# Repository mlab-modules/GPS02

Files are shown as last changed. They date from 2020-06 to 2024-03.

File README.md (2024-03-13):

# GPS02B - MLAB Module for RTK Navigation

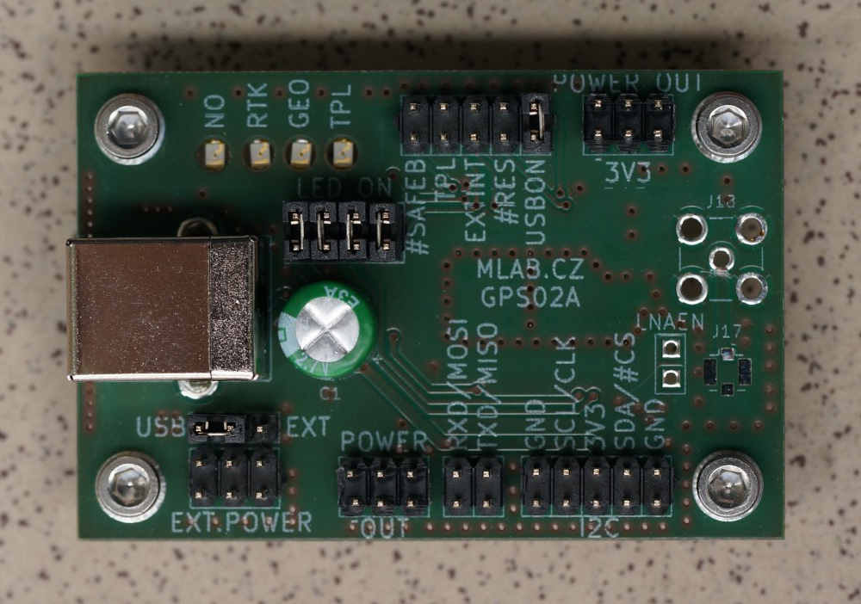
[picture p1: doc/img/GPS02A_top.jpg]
GPS02B


GPS02B is an accurate GNSS receiver module designed in the form of an MLAB module. This innovative design brings numerous advantages to the table, making it a choice for [RTK (Real-Time Kinematics)](https://en.wikipedia.org/wiki/Real-time_kinematic_positioning) navigation experiments. The GPS02B module is based on the uBlox receiver. There are multiple uBlox module types

  * [u-blox NEO-M8P](https://www.u-blox.com/en/product/neo-m8p-series) - With RTK functionality
  * [u-blox NEO-M9N](https://www.u-blox.com/en/product/neo-m9n-module) - High navigation rate GNSS module without RTK

The MLAB form factor provides several benefits for seamless integration and flexible usage. Here are some key advantages:

## Easy Integration and Compatibility

The GPS02B MLAB module follows the MLAB standard, making it easy to integrate into various MLAB-compatible systems and platforms. It ensures compatibility with other MLAB modules, allowing you to create custom configurations tailored to your specific requirements. The standardized pinout and interface simplify the process of connecting and interchanging modules within your MLAB ecosystem.

## Plug-and-Play Functionality

With its plug-and-play functionality, the GPS02B MLAB module simplifies the integration process. You can easily connect it to an MLAB system using standardized connectors, eliminating the need for complex wiring or soldering. This streamlined setup accelerates your development process and reduces time-to-market.

## Modular Expandability

The MLAB design philosophy revolves around modularity, enabling easy expansion and customization. The GPS02B module can be combined with other MLAB modules to enhance its capabilities or add new features. Whether you need additional sensors, communication interfaces, or processing power, the modular nature of MLAB allows for seamless expansion and adaptation to evolving project requirements.

## Robust and Reliable Construction

The GPS02B MLAB module is built to withstand demanding environments and provide reliable performance. Its sturdy construction ensures durability, making it suitable for applications that require long-term operation under challenging conditions. The module undergoes rigorous testing and quality control processes to deliver consistent and dependable results.

## Vast MLAB Ecosystem

By choosing the GPS02B MLAB module, you gain access to a vast ecosystem of MLAB modules and resources. The MLAB community offers a wide range of compatible modules, libraries, and development tools. You can leverage existing MLAB projects and community support to accelerate your development and benefit from the collective expertise of the MLAB community.

## Applications

The GPS02B MLAB module offers a wide range of applications in the field of RTK navigation and beyond. Here are a few examples:

- **Precision Agriculture**: Utilize the high-accuracy positioning capabilities of the GPS02B module for precise guidance of agricultural machinery, enabling optimized field operations and reduced input costs.

- **Geospatial Mapping**: Capture accurate geospatial data for surveying, mapping, and cartography applications. The GPS02B module provides reliable positioning information for creating detailed and precise maps.

- **Robotics**: Incorporate the GPS02B module into robotic systems for precise localization and navigation. Enable robots to navigate autonomously and perform tasks with high accuracy.

- **Asset Tracking**: Use the GPS02B module to track and monitor the movement of valuable assets in real-time, ensuring efficient logistics and enhanced security.

These are just a few examples of the many applications where the GPS02B MLAB module can be utilized. Its high accuracy, reliability, and compatibility with MLAB systems make it a versatile solution for a wide range of industries and projects.

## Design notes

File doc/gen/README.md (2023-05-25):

# PCB

Board size: 60.45x40.13 mm (2.38x1.58 inches)

- This is the size of the rectangle that contains the board
- Thickness: 1.6 mm (63 mils)
- Material: FR4
- Finish: None
- Layers: 2
- Copper thickness: 35 µm

Solder mask: TOP / BOTTOM

- Color: Green

Silk screen: TOP / BOTTOM

- Color: White

Stackup:

| Name | Type | Color | Thickness | Material | Epsilon_r | Loss tangent |
|---|---|---|---|---|---|---|
| F.SilkS | Top Silk Screen | | | | | |
| F.Paste | Top Solder Paste | | | | | |
| F.Mask | Top Solder Mask | Green | 10 | | | |
| F.Cu | copper | | 35 | | | |
| dielectric 1 | core | | 1510 | FR4 | 4.5 | 0.020 |
| B.Cu | copper | | 35 | | | |
| B.Mask | Bottom Solder Mask | Green | 10 | | | |
| B.Paste | Bottom Solder Paste  | | | | | |
| B.SilkS | Bottom Silk Screen | | | | | |

# Important sizes

Clearance: 0.2 mm (8 mils)

Track width: 0.4 mm (16 mils)

- By design rules: 0.4 mm (16 mils)

Drill: 0.5 mm (20 mils)

- Vias: 0.5 mm (20 mils) [Design: 0.4 mm (16 mils)]
- Pads: 0.9 mm (35 mils)
- The above values are real drill sizes, they add 0.1 mm (4 mils) to plated holes (PTH)

Via: 0.8/0.4 mm (31/16 mils)

- By design rules: 0.4/0.3 mm (16/12 mils)
- Micro via: no [0.2/0.1 mm (8/4 mils)]
- Buried/blind via: no
- Total: 192 (thru: 192 buried/blind: 0 micro: 0)

Outer Annular Ring: 0.15 mm (6 mils)

- By design rules: 0.15 mm (6 mils)

Eurocircuits class: 4B
- Using min drill 0.5 mm for an OAR of 0.15 mm

# General stats

Components count: (SMD/THT)

- Top: 0/28 (THT)
- Bottom: 35/0 (SMD)

Defined tracks:

- 0.4 mm (16 mils)
- 0.5 mm (20 mils)
- 0.6 mm (24 mils)
- 0.7 mm (28 mils)
- 0.86 mm (34 mils)
- 1.0 mm (39 mils)

Used tracks:

- 0.4 mm (16 mils) (206) defined: yes
- 0.5 mm (20 mils) (147) defined: yes
- 0.6 mm (24 mils) (34) defined: yes
- 0.7 mm (28 mils) (1) defined: yes
- 0.86 mm (34 mils) (4) defined: yes
- 1.0 mm (39 mils) (32) defined: yes

Defined vias:

- 0.8/0.4 mm (31/16 mils)

Used vias:

- 0.8/0.4 mm (31/16 mils) (Count: 192, Aspect: 2.0 A) defined: yes

Holes (excluding vias):

- 0.8 mm (31 mils) (2)
- 0.89 mm (35 mils) (55)
- 0.92 mm (36 mils) (4)
- 1.5 mm (59 mils) (1)
- 1.7 mm (67 mils) (4)
- 2.33 mm (92 mils) (2)
- 2.7 mm (106 mils) (4)
- 3.0 mm (118 mils) (4)

Oval holes:

Drill tools (including vias and computing adjusts and rounding):

- 0.5 mm (20 mils) (192)
- 0.9 mm (35 mils) (2)
- 1.0 mm (39 mils) (59)
- 1.6 mm (63 mils) (1)
- 1.8 mm (71 mils) (4)
- 2.45 mm (96 mils) (2)
- 2.7 mm (106 mils) (4)
- 3.1 mm (122 mils) (4)

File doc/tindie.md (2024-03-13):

## Unleash the Power of High-Accuracy Navigation

Discover the MLAB GPS02B, a precision GNSS (GPS) receiver module designed for Real-Time Kinematics (RTK) navigation. Embedded in the innovative [MLAB](https://www.mlab.cz/) (Modular Laboratory) form factor, the GPS02B is powered by the cutting-edge u-blox NEO-M8P receiver. It's engineered for professionals seeking unparalleled accuracy and reliability in their navigation applications.

### Key Features:

- **Seamless Integration**: Adhering to the MLAB standard, GPS02B ensures hassle-free integration into any MLAB-compatible system, fostering a plug-and-play setup that accelerates development timelines.

- **Expandability**: Embrace the modular MLAB philosophy for easy system customization. Enhance your project with additional sensors, communication interfaces, or processors, all while maintaining system coherence.

- **Durability and Reliability**: Constructed to endure, the GPS02B is your go-to module for projects demanding long-term stability in harsh conditions. It stands as a testament to unwavering performance through rigorous testing.

- **MLAB Ecosystem Access**: Tap into an extensive ecosystem of modules, libraries, and tools within the MLAB community. Benefit from shared knowledge and resources to push your projects beyond the boundaries.

### Application Domains:

- **Precision Agriculture**: Elevate farming efficiency with GPS02B's high-accuracy positioning, enabling smart guidance for agricultural machines to optimize operations and reduce costs.

- **Geospatial Mapping**: Achieve meticulous geospatial data collection for surveying and mapping, with the GPS02B ensuring the precision required for detailed cartographic outputs.

- **Advanced Robotics**: Empower robotic systems with precise localization and navigation capabilities, enabling autonomous operation and task execution with exceptional accuracy.

- **Real-Time Asset Tracking**: Implement GPS02B for steadfast tracking of valuable assets, enhancing logistics and security through real-time, accurate monitoring.

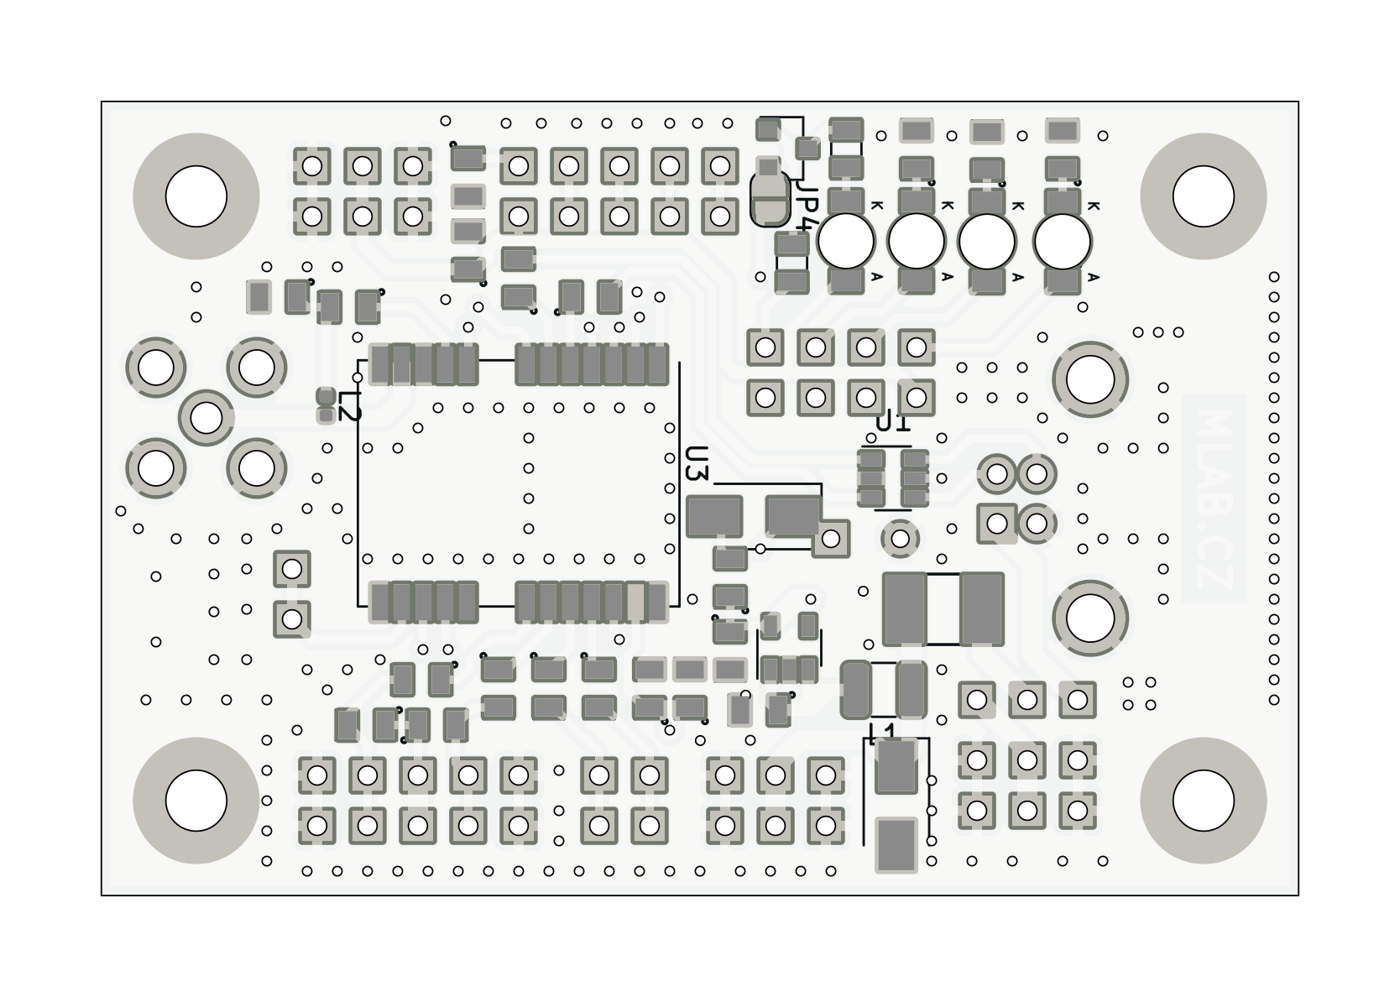
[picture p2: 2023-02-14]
doc/gen/img/GPS02B-bottom.png

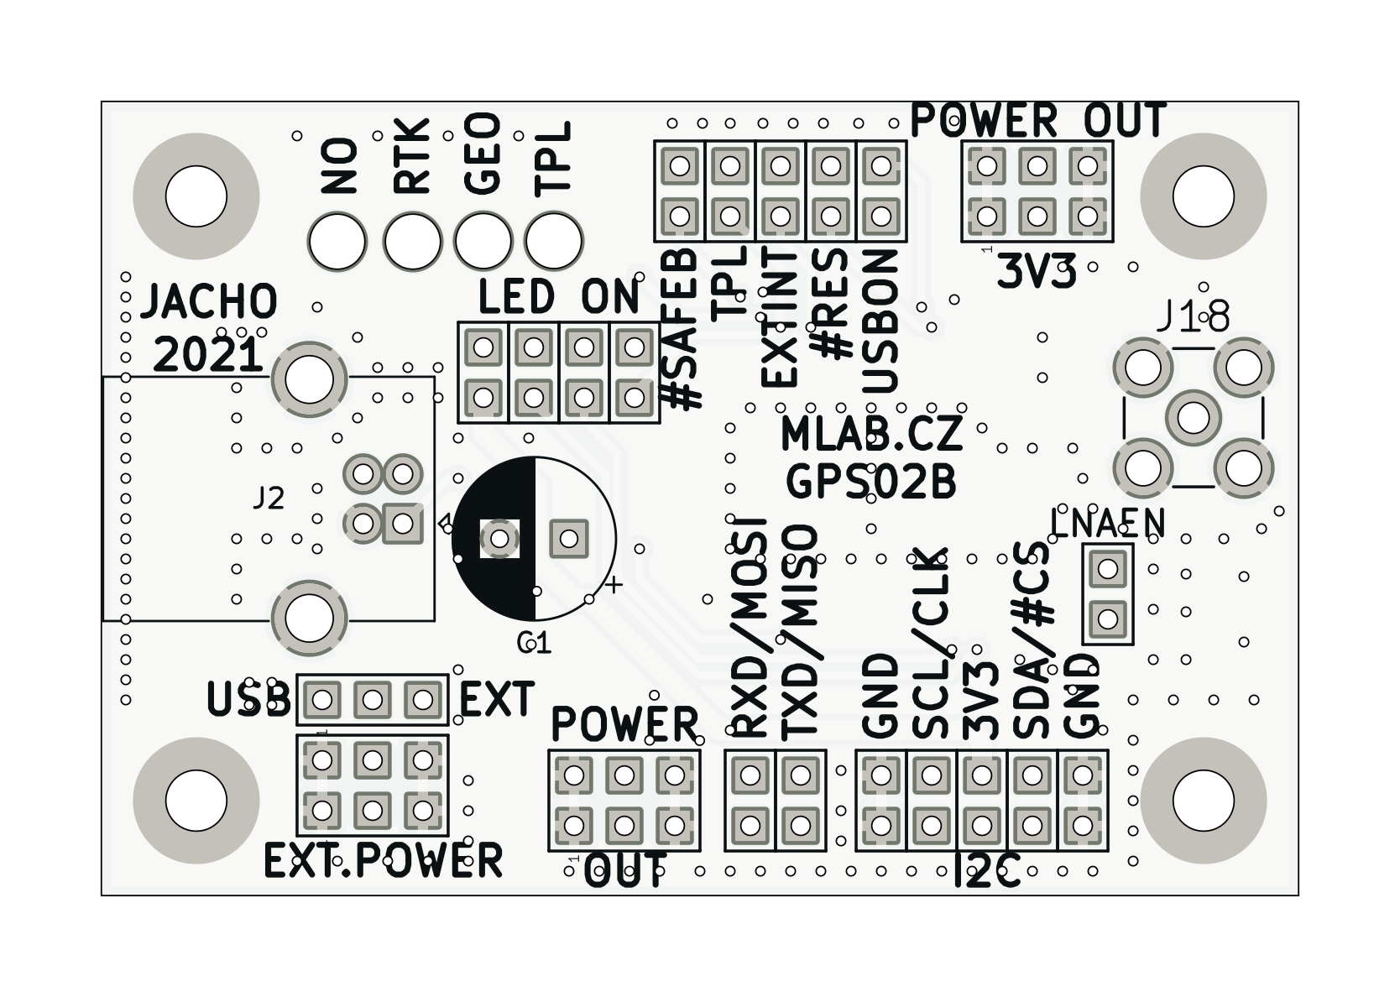
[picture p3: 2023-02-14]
doc/gen/img/GPS02B-top.png

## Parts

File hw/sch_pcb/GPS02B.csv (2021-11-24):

Source: | F:\MLAB_G\Moduly_zvlast\GPS02\hw\sch_pcb\GPS02B.kicad_sch
Date: | 24.11.2021 11:09:11
Tool: | Eeschema (5.99.0-13046-g4fe9f01eb0)
Generator: | C:\Program Files\KiCad\5.99\bin\scripting\plugins/bom_csv_grouped_by_value.py
Component Count: | 64
Individual Components:
Item | Qty | Reference(s) | Value | LibPart | Footprint | Datasheet | UST_ID
 |  | C1 | 1F | GPS02A-rescue:CP-Device | Capacitor_THT:CP_Radial_D8.0mm_P3.50mm |  | 5c70984412875079b91f8873
 |  | C2 | 10uF | GPS02A-rescue:C-Device | Mlab_R:SMD-0805 |  | 5c70984812875079b91f8bbe
 |  | C3 | 1uF | GPS02A-rescue:C-Device | Mlab_R:SMD-0805 |  | 5c70984712875079b91f8b50
 |  | C4 | 100nF | GPS02A-rescue:C-Device | Mlab_R:SMD-0805 |  | 5c70984712875079b91f8b4c
 |  | C5 | 1uF | GPS02A-rescue:C-Device | Mlab_R:SMD-0805 |  | 5c70984712875079b91f8b50
 |  | C6 | 1uF | GPS02A-rescue:C-Device | Mlab_R:SMD-0805 |  | 5c70984712875079b91f8b50
 |  | C7 | 47pF | GPS02A-rescue:C-Device | Mlab_R:SMD-0805 |  | 5c70984712875079b91f8b38
 |  | D1 | M4 | GPS02A-rescue:D_Zener-Device | Diode_SMD:D_SMA |  | 5c70984512875079b91f88ac
 |  | D2 | M4 | GPS02A-rescue:D-Device | Diode_SMD:D_SMA |  | 5c70984512875079b91f88ac
 |  | D3 | RED | GPS02A-rescue:LED-Device | Mlab_D:LED_1206 |  | 5c70984412875079b91f8896
 |  | D4 | YELLOW | GPS02A-rescue:LED-Device | Mlab_D:LED_1206 |  | 5c70984412875079b91f8897
 |  | D5 | YELLOW | GPS02A-rescue:LED-Device | Mlab_D:LED_1206 |  | 5c70984412875079b91f8897
 |  | D6 | GREEN | GPS02A-rescue:LED-Device | Mlab_D:LED_1206 |  | 5c70984412875079b91f8895
 |  | F1 | 750mA | GPS02A-rescue:Fuse-Device | Mlab_F:1812 |  | 5c70984512875079b91f88d2
 |  | J1 | HEADER_2x03_PARALLEL | MLAB_HEADER:HEADER_2x03_PARALLEL | Mlab_Pin_Headers:Straight_2x03
 |  | J2 | USB_B | GPS02A-rescue:USB_B-Connector | Connector_USB:USB_B_OST_USB-B1HSxx_Horizontal | ~ | 5c70984412875079b91f87a8
 |  | J3 | HEADER_2x03_PARALLEL | MLAB_HEADER:HEADER_2x03_PARALLEL | Mlab_Pin_Headers:Straight_2x03
 |  | J4 | HEADER_2x01_PARALLEL | MLAB_HEADER:HEADER_2x01_PARALLEL | Mlab_Pin_Headers:Straight_2x01
 |  | J5 | HEADER_2x01_PARALLEL | MLAB_HEADER:HEADER_2x01_PARALLEL | Mlab_Pin_Headers:Straight_2x01
 |  | J6 | HEADER_2x01_PARALLEL | MLAB_HEADER:HEADER_2x01_PARALLEL | Mlab_Pin_Headers:Straight_2x01
 |  | J7 | HEADER_2x01_PARALLEL | MLAB_HEADER:HEADER_2x01_PARALLEL | Mlab_Pin_Headers:Straight_2x01
 |  | J8 | HEADER_2x01_PARALLEL | MLAB_HEADER:HEADER_2x01_PARALLEL | Mlab_Pin_Headers:Straight_2x01
 |  | J9 | HEADER_2x01_PARALLEL | MLAB_HEADER:HEADER_2x01_PARALLEL | Mlab_Pin_Headers:Straight_2x01
 |  | J10 | HEADER_2x01_PARALLEL | MLAB_HEADER:HEADER_2x01_PARALLEL | Mlab_Pin_Headers:Straight_2x01
 |  | J11 | HEADER_2x01_PARALLEL | MLAB_HEADER:HEADER_2x01_PARALLEL | Mlab_Pin_Headers:Straight_2x01
 |  | J12 | HEADER_2x01_PARALLEL | MLAB_HEADER:HEADER_2x01_PARALLEL | Mlab_Pin_Headers:Straight_2x01
 |  | J13 | HEADER_2x01_PARALLEL | MLAB_HEADER:HEADER_2x01_PARALLEL | Mlab_Pin_Headers:Straight_2x01
 |  | J14 | HEADER_2x01_PARALLEL | MLAB_HEADER:HEADER_2x01_PARALLEL | Mlab_Pin_Headers:Straight_2x01
 |  | J15 | HEADER_2x03_PARALLEL | MLAB_HEADER:HEADER_2x03_PARALLEL | Mlab_Pin_Headers:Straight_2x03
 |  | J16 | HEADER_2x01_PARALLEL | MLAB_HEADER:HEADER_2x01_PARALLEL | Mlab_Pin_Headers:Straight_2x01
 |  | J18 | SMA | GPS02A-rescue:SMA-MLAB_CONNECTORS | Mlab_CON:SMA6251A13G50 |  | 5c70984412875079b91f87ac
 |  | JP1 | Jumper_3_Bridged12 | GPS02A-rescue:Jumper_3_Bridged12-Jumper | Mlab_Pin_Headers:Straight_1x03
 |  | JP2 | Jumper_2_Bridged | GPS02A-rescue:Jumper_2_Bridged-Jumper | Mlab_Pin_Headers:Straight_1x02
 |  | JP4 | Jumper_2_Open | GPS02A-rescue:Jumper_2_Open-Jumper | Jumper:SolderJumper-2_P1.3mm_Open_RoundedPad1.0x1.5mm
 |  | JP6 | Jumper_2_Bridged | GPS02A-rescue:Jumper_2_Bridged-Jumper | Mlab_Pin_Headers:Straight_1x02
 |  | JP7 | Jumper_2_Open | GPS02A-rescue:Jumper_2_Open-Jumper | Mlab_Pin_Headers:Straight_1x02
 |  | JP8 | Jumper_2_Open | GPS02A-rescue:Jumper_2_Open-Jumper | Mlab_Pin_Headers:Straight_1x02
 |  | JP9 | Jumper_2_Open | GPS02A-rescue:Jumper_2_Open-Jumper | Mlab_Pin_Headers:Straight_1x02
 |  | L1 | NL322522T-101K | GPS02A-rescue:L-Device | Inductor_SMD:L_1210_3225Metric |  | 5c70984412875079b91f87fb
 |  | L2 | 27nH | GPS02A-rescue:L-Device | Inductor_SMD:L_0402_1005Metric | LQG15HS27NJ02D | 618cbf071287506e2801ed7e
 |  | M1 | HOLE | MLAB_MECHANICAL:HOLE | Mlab_Mechanical:MountingHole_3mm
 |  | M2 | HOLE | MLAB_MECHANICAL:HOLE | Mlab_Mechanical:MountingHole_3mm
 |  | M3 | HOLE | MLAB_MECHANICAL:HOLE | Mlab_Mechanical:MountingHole_3mm
 |  | M4 | HOLE | MLAB_MECHANICAL:HOLE | Mlab_Mechanical:MountingHole_3mm
 |  | Q1 | BC817-25 | Device:Q_NPN_BEC | Package_TO_SOT_SMD:SOT-23 | ~ | 5c70984712875079b91f8aea
 |  | R1 | 22R | GPS02A-rescue:R-Device | Mlab_R:SMD-0805 |  | 5c70984512875079b91f896f
 |  | R2 | 10k | GPS02A-rescue:R-Device | Mlab_R:SMD-0805 |  | 5c70984612875079b91f899f
 |  | R3 | 10k | GPS02A-rescue:R-Device | Mlab_R:SMD-0805 |  | 5c70984612875079b91f899f
 |  | R4 | 33R | GPS02A-rescue:R-Device | Mlab_R:SMD-0805 |  | 5c70984512875079b91f8970
 |  | R5 | 33R | GPS02A-rescue:R-Device | Mlab_R:SMD-0805 |  | 5c70984512875079b91f8970
 |  | R6 | 33R | GPS02A-rescue:R-Device | Mlab_R:SMD-0805 |  | 5c70984512875079b91f8970
 |  | R7 | 33R | GPS02A-rescue:R-Device | Mlab_R:SMD-0805 |  | 5c70984512875079b91f8970
 |  | R8 | 33R | GPS02A-rescue:R-Device | Mlab_R:SMD-0805 |  | 5c70984512875079b91f8970
 |  | R9 | 33R | GPS02A-rescue:R-Device | Mlab_R:SMD-0805 |  | 5c70984512875079b91f8970
 |  | R10 | 620R | GPS02A-rescue:R-Device | Mlab_R:SMD-0805 |  | 5c70984512875079b91f8989
 |  | R11 | 10R | GPS02A-rescue:R-Device | Mlab_R:SMD-0805 |  | 5c70984512875079b91f896d
 |  | R12 | 620R | GPS02A-rescue:R-Device | Mlab_R:SMD-0805 |  | 5c70984512875079b91f8989
 |  | R13 | 620R | GPS02A-rescue:R-Device | Mlab_R:SMD-0805 |  | 5c70984512875079b91f8989
 |  | R14 | 220R | Device:R | Mlab_R:SMD-0805 | ~ | 5c70984512875079b91f897f
 |  | R15 | 10k | GPS02A-rescue:R-Device | Mlab_R:SMD-0805 |  | 5c70984612875079b91f899f
 |  | R16 | 220R | Device:R | Mlab_R:SMD-0805 | ~ | 5c70984512875079b91f897f
 |  | U1 | USBLC6-2SC6 | GPS02A-rescue:USBLC6-2SC6-Power_Protection | Package_TO_SOT_SMD:SOT-23-6 | http://www2.st.com/resource/en/datasheet/CD00050750.pdf | 5e82e0691287502a334a778c
 |  | U2 | MIC5504-3.3YM5 | GPS02A-rescue:MIC5504-3.3YM5-Regulator_Linear | Package_TO_SOT_SMD:SOT-23-5 | http://ww1.microchip.com/downloads/en/DeviceDoc/MIC550X.pdf | 5c7255e81287500b4e112ea2
 |  | U3 | NEO-M8P | GPS02A-rescue:NEO-M8P-RF_GPS | RF_GPS:ublox_NEO | https://www.u-blox.com/sites/default/files/NEO-M8P_DataSheet_%28UBX-15016656%29.pdf | 5ed7ad5612875004e15a62f5
Collated Components:
Item | Qty | Reference(s) | Value | LibPart | Footprint | Datasheet | UST_ID
1 | 1 | C1 | 1F | GPS02A-rescue:CP-Device | Capacitor_THT:CP_Radial_D8.0mm_P3.50mm |  | 5c70984412875079b91f8873
2 | 1 | C2 | 10uF | GPS02A-rescue:C-Device | Mlab_R:SMD-0805 |  | 5c70984812875079b91f8bbe
3 | 3 | C3, C5, C6 | 1uF | GPS02A-rescue:C-Device | Mlab_R:SMD-0805 |  | 5c70984712875079b91f8b50
4 | 1 | C4 | 100nF | GPS02A-rescue:C-Device | Mlab_R:SMD-0805 |  | 5c70984712875079b91f8b4c
5 | 1 | C7 | 47pF | GPS02A-rescue:C-Device | Mlab_R:SMD-0805 |  | 5c70984712875079b91f8b38
6 | 1 | D1 | M4 | GPS02A-rescue:D_Zener-Device | Diode_SMD:D_SMA |  | 5c70984512875079b91f88ac
7 | 1 | D2 | M4 | GPS02A-rescue:D-Device | Diode_SMD:D_SMA |  | 5c70984512875079b91f88ac
8 | 1 | D3 | RED | GPS02A-rescue:LED-Device | Mlab_D:LED_1206 |  | 5c70984412875079b91f8896
9 | 2 | D4, D5 | YELLOW | GPS02A-rescue:LED-Device | Mlab_D:LED_1206 |  | 5c70984412875079b91f8897
10 | 1 | D6 | GREEN | GPS02A-rescue:LED-Device | Mlab_D:LED_1206 |  | 5c70984412875079b91f8895
11 | 1 | F1 | 750mA | GPS02A-rescue:Fuse-Device | Mlab_F:1812 |  | 5c70984512875079b91f88d2
12 | 3 | J1, J3, J15 | HEADER_2x03_PARALLEL | MLAB_HEADER:HEADER_2x03_PARALLEL | Mlab_Pin_Headers:Straight_2x03
13 | 1 | J2 | USB_B | GPS02A-rescue:USB_B-Connector | Connector_USB:USB_B_OST_USB-B1HSxx_Horizontal | ~ | 5c70984412875079b91f87a8
14 | 12 | J4, J5, J6, J7, J8, J9, J10, J11, J12, J13, J14, J16 | HEADER_2x01_PARALLEL | MLAB_HEADER:HEADER_2x01_PARALLEL | Mlab_Pin_Headers:Straight_2x01
15 | 1 | J18 | SMA | GPS02A-rescue:SMA-MLAB_CONNECTORS | Mlab_CON:SMA6251A13G50 |  | 5c70984412875079b91f87ac
16 | 1 | JP1 | Jumper_3_Bridged12 | GPS02A-rescue:Jumper_3_Bridged12-Jumper | Mlab_Pin_Headers:Straight_1x03
17 | 2 | JP2, JP6 | Jumper_2_Bridged | GPS02A-rescue:Jumper_2_Bridged-Jumper | Mlab_Pin_Headers:Straight_1x02
18 | 1 | JP4 | Jumper_2_Open | GPS02A-rescue:Jumper_2_Open-Jumper | Jumper:SolderJumper-2_P1.3mm_Open_RoundedPad1.0x1.5mm
19 | 3 | JP7, JP8, JP9 | Jumper_2_Open | GPS02A-rescue:Jumper_2_Open-Jumper | Mlab_Pin_Headers:Straight_1x02
20 | 1 | L1 | NL322522T-101K | GPS02A-rescue:L-Device | Inductor_SMD:L_1210_3225Metric |  | 5c70984412875079b91f87fb
21 | 1 | L2 | 27nH | GPS02A-rescue:L-Device | Inductor_SMD:L_0402_1005Metric | LQG15HS27NJ02D | 618cbf071287506e2801ed7e
22 | 4 | M1, M2, M3, M4 | HOLE | MLAB_MECHANICAL:HOLE | Mlab_Mechanical:MountingHole_3mm
23 | 1 | Q1 | BC817-25 | Device:Q_NPN_BEC | Package_TO_SOT_SMD:SOT-23 | ~ | 5c70984712875079b91f8aea
24 | 1 | R1 | 22R | GPS02A-rescue:R-Device | Mlab_R:SMD-0805 |  | 5c70984512875079b91f896f
25 | 3 | R2, R3, R15 | 10k | GPS02A-rescue:R-Device | Mlab_R:SMD-0805 |  | 5c70984612875079b91f899f
26 | 6 | R4, R5, R6, R7, R8, R9 | 33R | GPS02A-rescue:R-Device | Mlab_R:SMD-0805 |  | 5c70984512875079b91f8970
27 | 3 | R10, R12, R13 | 620R | GPS02A-rescue:R-Device | Mlab_R:SMD-0805 |  | 5c70984512875079b91f8989
28 | 1 | R11 | 10R | GPS02A-rescue:R-Device | Mlab_R:SMD-0805 |  | 5c70984512875079b91f896d
29 | 2 | R14, R16 | 220R | Device:R | Mlab_R:SMD-0805 | ~ | 5c70984512875079b91f897f
30 | 1 | U1 | USBLC6-2SC6 | GPS02A-rescue:USBLC6-2SC6-Power_Protection | Package_TO_SOT_SMD:SOT-23-6 | http://www2.st.com/resource/en/datasheet/CD00050750.pdf | 5e82e0691287502a334a778c
31 | 1 | U2 | MIC5504-3.3YM5 | GPS02A-rescue:MIC5504-3.3YM5-Regulator_Linear | Package_TO_SOT_SMD:SOT-23-5 | http://ww1.microchip.com/downloads/en/DeviceDoc/MIC550X.pdf | 5c7255e81287500b4e112ea2
32 | 1 | U3 | NEO-M8P | GPS02A-rescue:NEO-M8P-RF_GPS | RF_GPS:ublox_NEO | https://www.u-blox.com/sites/default/files/NEO-M8P_DataSheet_%28UBX-15016656%29.pdf | 5ed7ad5612875004e15a62f5

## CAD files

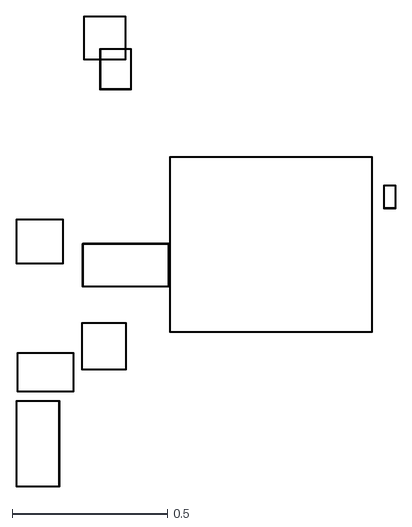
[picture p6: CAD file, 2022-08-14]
doc/gen/dxf/GPS02B-B_Courtyard.dxf
1.22 x 1.51

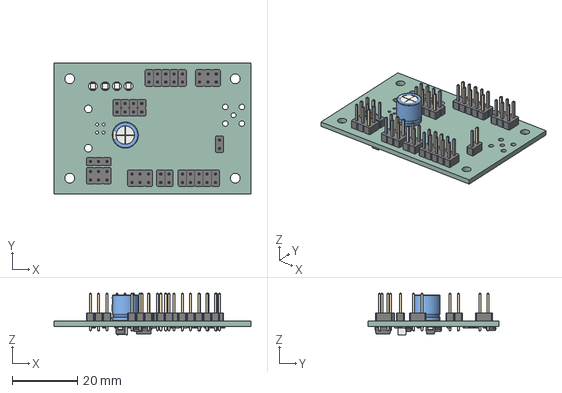
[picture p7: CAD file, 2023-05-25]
doc/gen/GPS02B.step
60.5 x 40.1 x 12.7 mm
tmpdh7f3xjg PCB

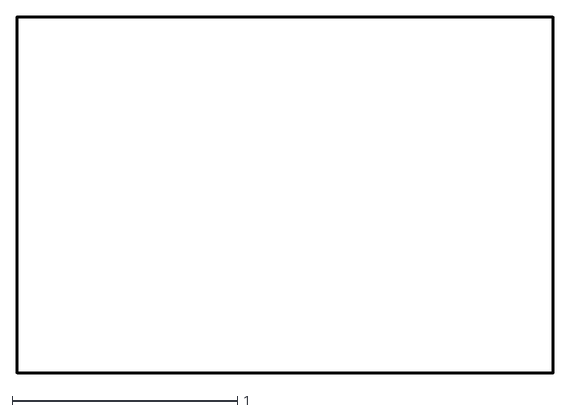
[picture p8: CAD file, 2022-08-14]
doc/gen/dxf/GPS02B-Edge_Cuts.dxf
2.39 x 1.59

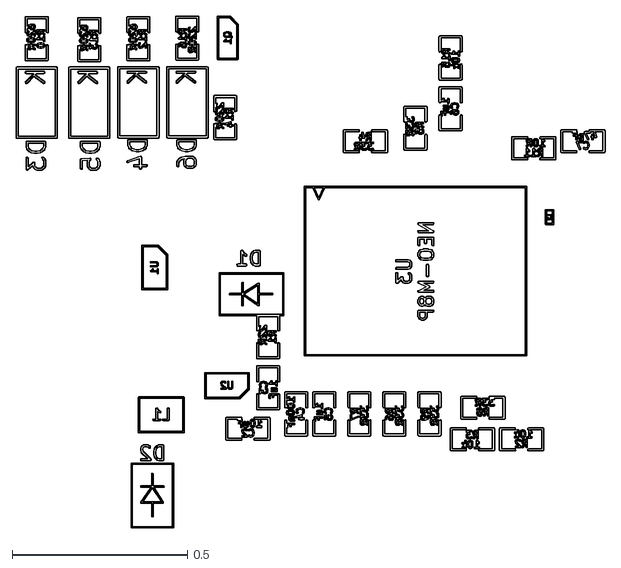
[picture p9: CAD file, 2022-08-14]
doc/gen/dxf/GPS02B-B_Fab.dxf
1.68 x 1.46

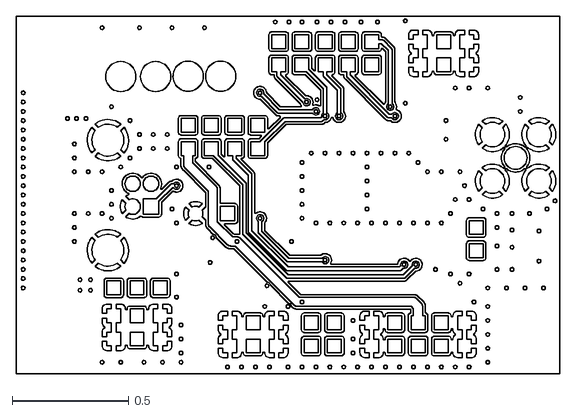
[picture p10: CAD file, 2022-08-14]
doc/gen/dxf/GPS02B-F_Cu.dxf
2.34 x 1.54

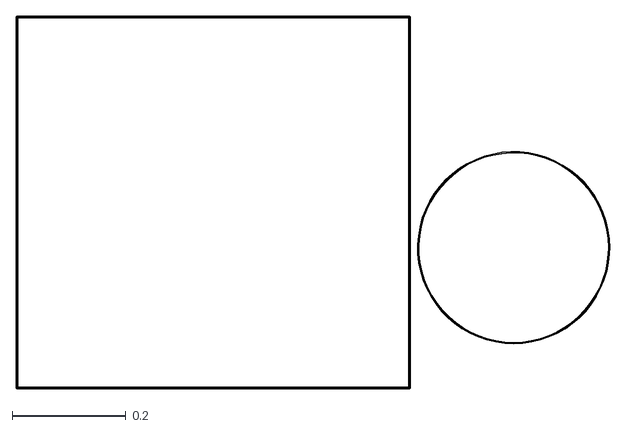
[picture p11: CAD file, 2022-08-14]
doc/gen/dxf/GPS02B-F_Courtyard.dxf
1.04 x 0.653

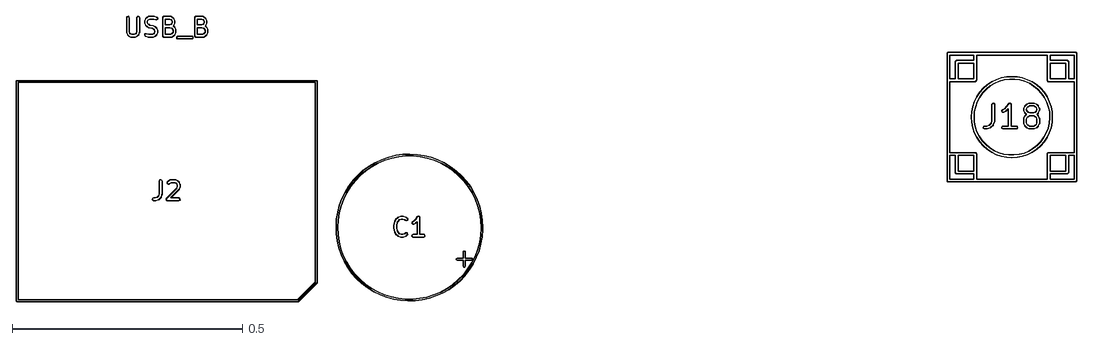
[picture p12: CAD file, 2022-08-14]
doc/gen/dxf/GPS02B-F_Fab.dxf
2.30 x 0.62

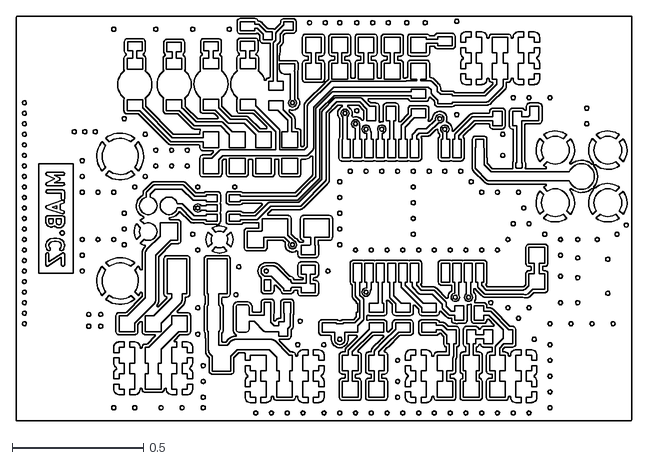
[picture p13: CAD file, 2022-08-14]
doc/gen/dxf/GPS02B-B_Cu.dxf
2.34 x 1.54

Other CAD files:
doc/gen/dxf/GPS02B-Margin.dxf
doc/gen/dxf/GPS02B-B_Mask.dxf
doc/gen/dxf/GPS02B-B_Paste.dxf
doc/gen/dxf/GPS02B-B_Silkscreen.dxf
doc/gen/dxf/GPS02B-F_Mask.dxf
doc/gen/dxf/GPS02B-F_Paste.dxf
doc/gen/dxf/GPS02B-F_Silkscreen.dxf

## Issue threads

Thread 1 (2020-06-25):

Připojení GPS antény

kaklik, 2020-06-25:
GPS anténa má na modulu možnost připojení přes SMA konektor a U.fl konektor.

@ChroustJan  při výrobě odrvrtal prostřední pin, protože otvor v KiCAD knihovnách je pro skladovou verzi SMA konektoru příliš malý.

Během výroby modulu jsme se ale rozhodli začít používat konektory [MCX](https://en.wikipedia.org/wiki/MCX_connector). Které ale mají středový pin s menším průměrem. Odvrtávání tak pravděpodobně není potřeba.

Před přiletováním MCX konektoru jsem proškrabal cestičku k ploškám U.fl, aby zbytečně nekazila parametry přívodu.

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

ChroustJan, 2021-03-14:
@kaklik co s tímto issues?

kaklik, 2021-03-14:
> @kaklik co s tímto issues?

Smazat u.fl konektor a nějak optimalizovat průměr otvoru pro středový pin.

ChroustJan, 2021-03-14:
@kaklik a to tedy u.fl konektor vyřazujeme?

kaklik, 2021-03-14:
> @kaklik a to tedy u.fl konektor vyřazujeme?

Já pro u.fl konektor nevidím na MLAB modulech využití..  Ty jsi ho někdy někde použil?

ChroustJan, 2021-03-15:
@kaklik  mělo to být řešení pro zařízení, aby se nepovolovalo SMA, ale tohle v zásadě řeší i ten nový konektor. Prodávají se k němu i redukce o 90stupňů? Aby se nám to pak vešlo do Al krabičky.

kaklik, 2021-06-20:
> @kaklik mělo to být řešení pro zařízení, aby se nepovolovalo SMA, ale tohle v zásadě řeší i ten nový konektor. Prodávají se k němu i redukce o 90stupňů? Aby se nám to pak vešlo do Al krabičky.

Tenhle problém myslím řeší nové MLAB kabely se zahnutými MCX konektory z výroby.

ChroustJan, 2021-07-20:
U.fl konektor odstraněn.

Closed 2021-07-20.

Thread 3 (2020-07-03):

Přebíjení zálohovacího kondenzátoru

kaklik, 2020-07-03:
Zálohovací kondenzátor je nabíjen na hodnotu 3.07 V. Maximální přípustná hodnota napětí na kondezátoru však je 2.7 V

Příčinou přebíjení je fakt, že kondenzátor je nabíjen přes shottkyho diodu BAS85, která má napěťový úbytek pouze 0.2V

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

K odstranění tohoto problému je nutné použít nějakou normální křemíkovou diodu s napěťovým úbytkem alespoň 0.5V.

ChroustJan, 2020-07-08:
Tak už víme, proč tam byla ta jiná dioda, která se ti nezdála.

ChroustJan, 2021-07-20:
Aplikována dioda M4

Closed 2021-07-20.

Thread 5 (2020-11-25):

Upravit otvor pro SMA konektor

ChroustJan, 2020-11-25:
Upravit otvory na SMA dle starých MLAB knihoven.

Viz issue #1

kaklik, 2020-11-25:
Proč? Teď máme stejně MCX..

ChroustJan, 2020-11-25:
Považuji za rozumné mít tu možnost. Nevychází to o chlup. Kicad má pro nás nevyhovující knihovnu.

ChroustJan, 2021-07-20:
Provedeno.

Closed 2021-07-20.

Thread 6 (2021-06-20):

Napájení aktivní antény

kaklik, 2021-06-20:
Při experimentech se ukázalo, že GNSS přijímač NEO-M8P má časté výpadky fixu. S tím, že úroveň signálu se celou dobu provozu drží mírně nad hranicí navigace.

Z konstrukčního pohledu je podezřelý způsob, kterým je vyřešeno napájení aktivní antény. Ve schéma je tento obvod:

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

Na PCB je zapojení realizováno tímto layoutem:

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

Zapojení je pravděpodobně  převzato z [aplikačního manuálu NEO-M8P](https://www.u-blox.com/en/docs/UBX-15028081), kde je následující obrázek:
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

Ten odkazuje jednak na záležitost, že je vhodné dát na vstup RF_IN střídavou vazbu, aby byl vstup lépe ESD ochráněn. (popsáno v sekci 3.3 Figure  11: ESD precautions)

A potom také odkazuje na tabulku doporučených hodnot součástek:

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

Z tabulky je vidět, že zřejména použitý kondenzátor zjevně nesplňuje doporučené parametry, neboť tabulka uvažuje kapacitu o hodnotě 47pF místo 10nF, což je celkem očekávatelné vzhledem k doporučené hodnotě indukčnosti. Kde se na cívku kromě doporučené hodnoty 27nH klade ještě další požadavek, aby měla impedanci větší než 500 ohm na potřebných GPS frekvencích.

Celkově je tak potřeba:

- [ ] Posunout cívku L2 tak, aby co nejméně narušovala RF cestu k anténě
- [ ] Změnit hodnotu kondenzátoru C7 na 47pF
- [ ] Ověřit katalogové parametry použité cívky.

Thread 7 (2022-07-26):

RTK_STAT LED inverted

kaklik, 2022-07-26:
There should be an inverting transistor on RTK_STAT output. It is because the RTK LED light up after power up, then blinks, and in the RTK fixed mode switch off.

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

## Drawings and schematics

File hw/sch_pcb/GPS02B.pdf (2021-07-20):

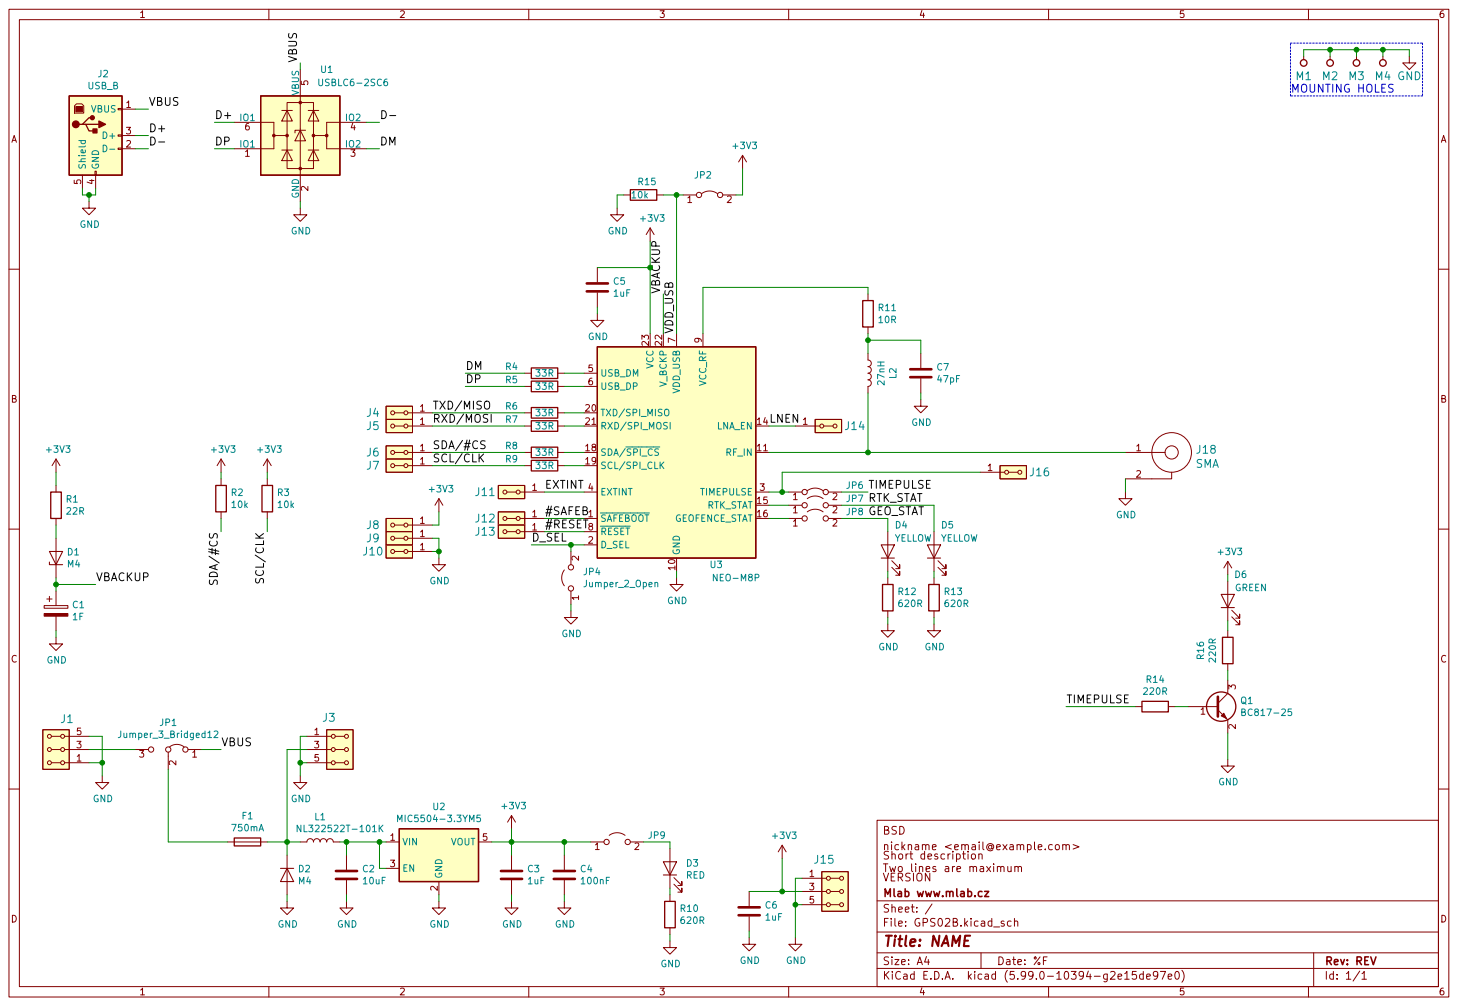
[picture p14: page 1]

nickname <email@example.com> BSD

Short description
File: GPS02B.kicad_sch Sheet: / Mlab www.mlab.cz VERSION

Two lines are maximum

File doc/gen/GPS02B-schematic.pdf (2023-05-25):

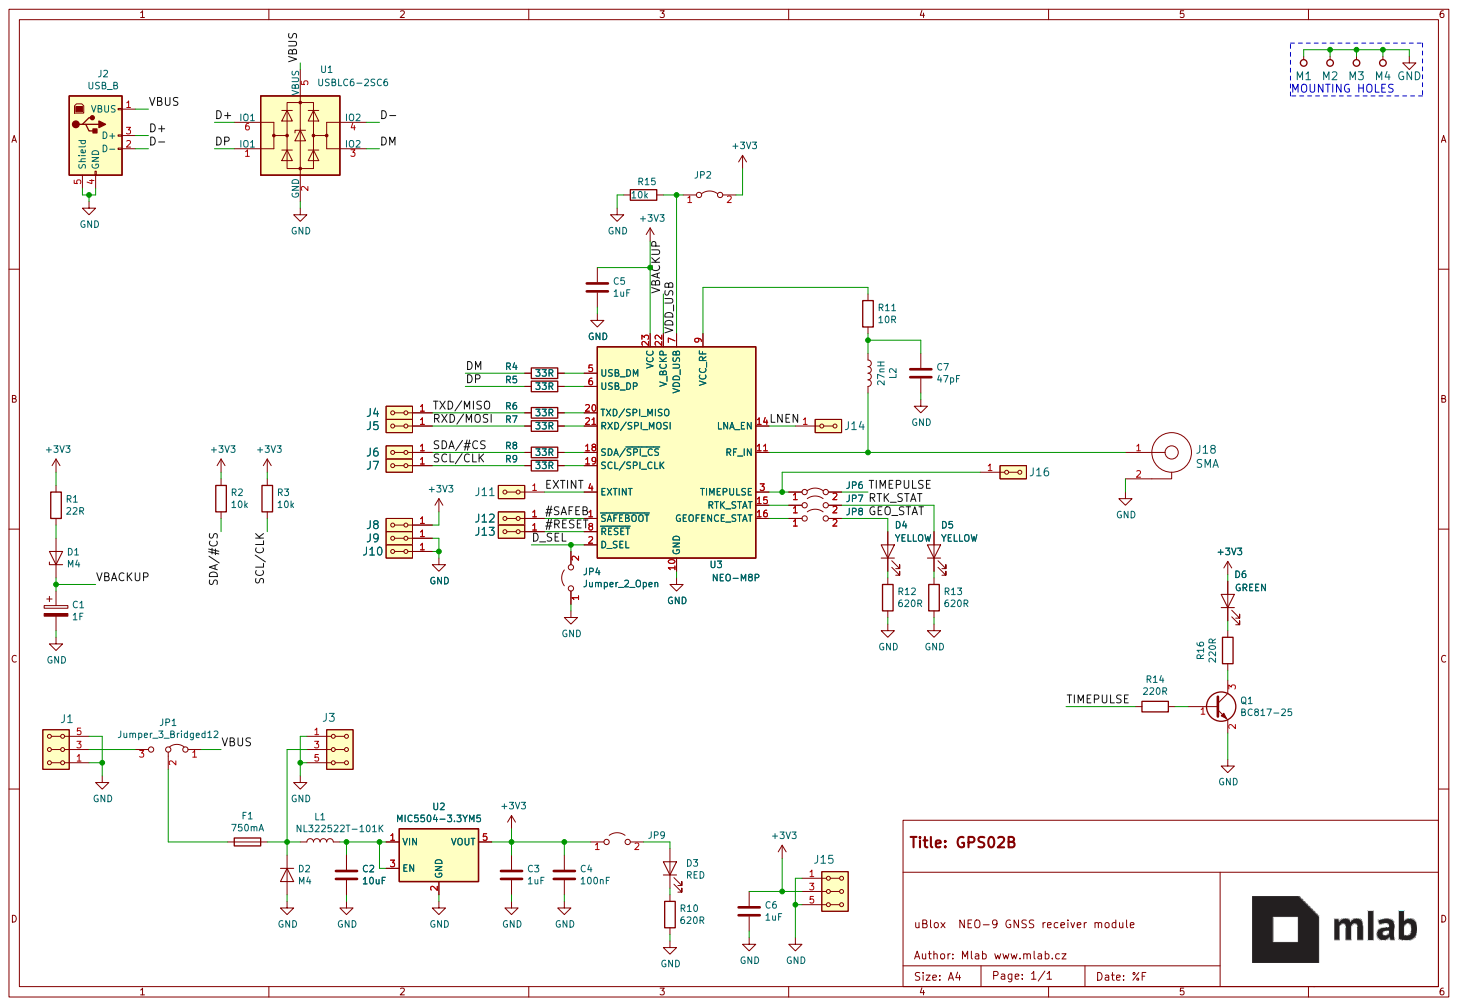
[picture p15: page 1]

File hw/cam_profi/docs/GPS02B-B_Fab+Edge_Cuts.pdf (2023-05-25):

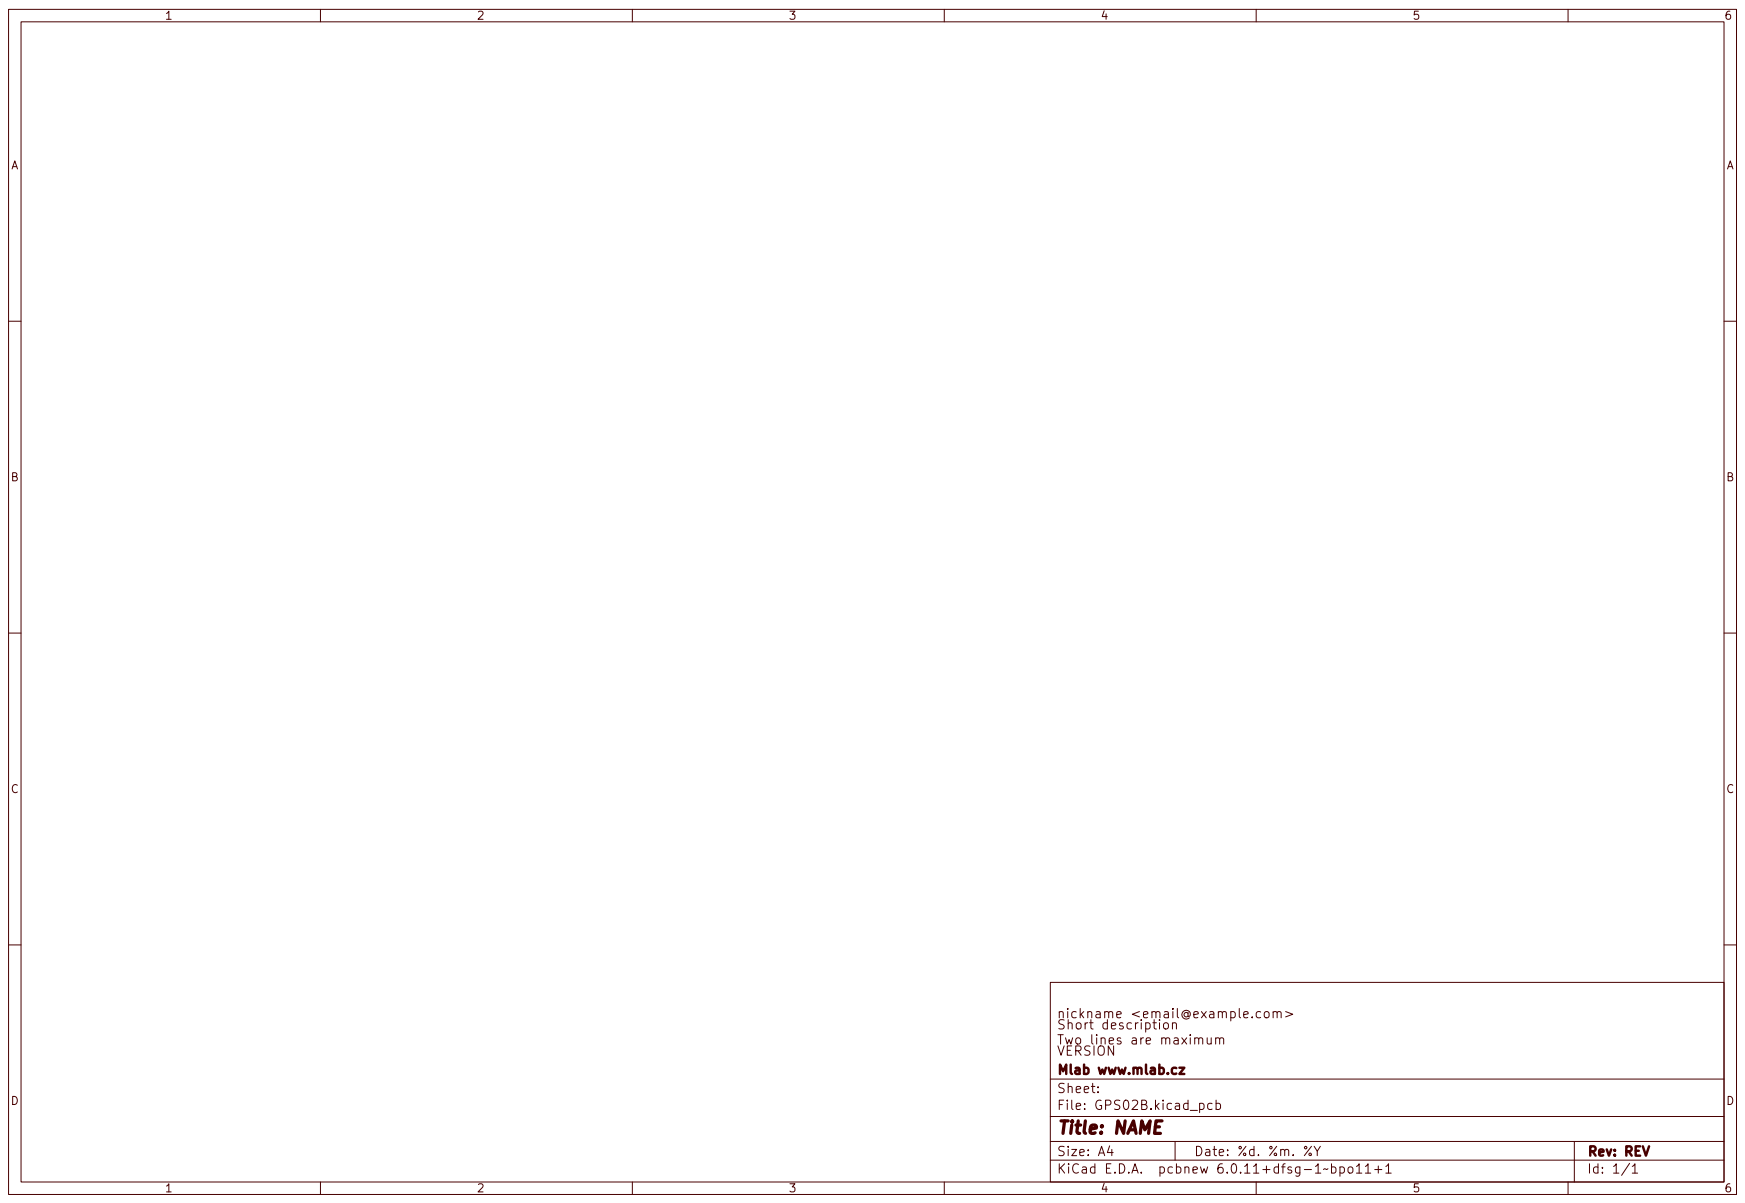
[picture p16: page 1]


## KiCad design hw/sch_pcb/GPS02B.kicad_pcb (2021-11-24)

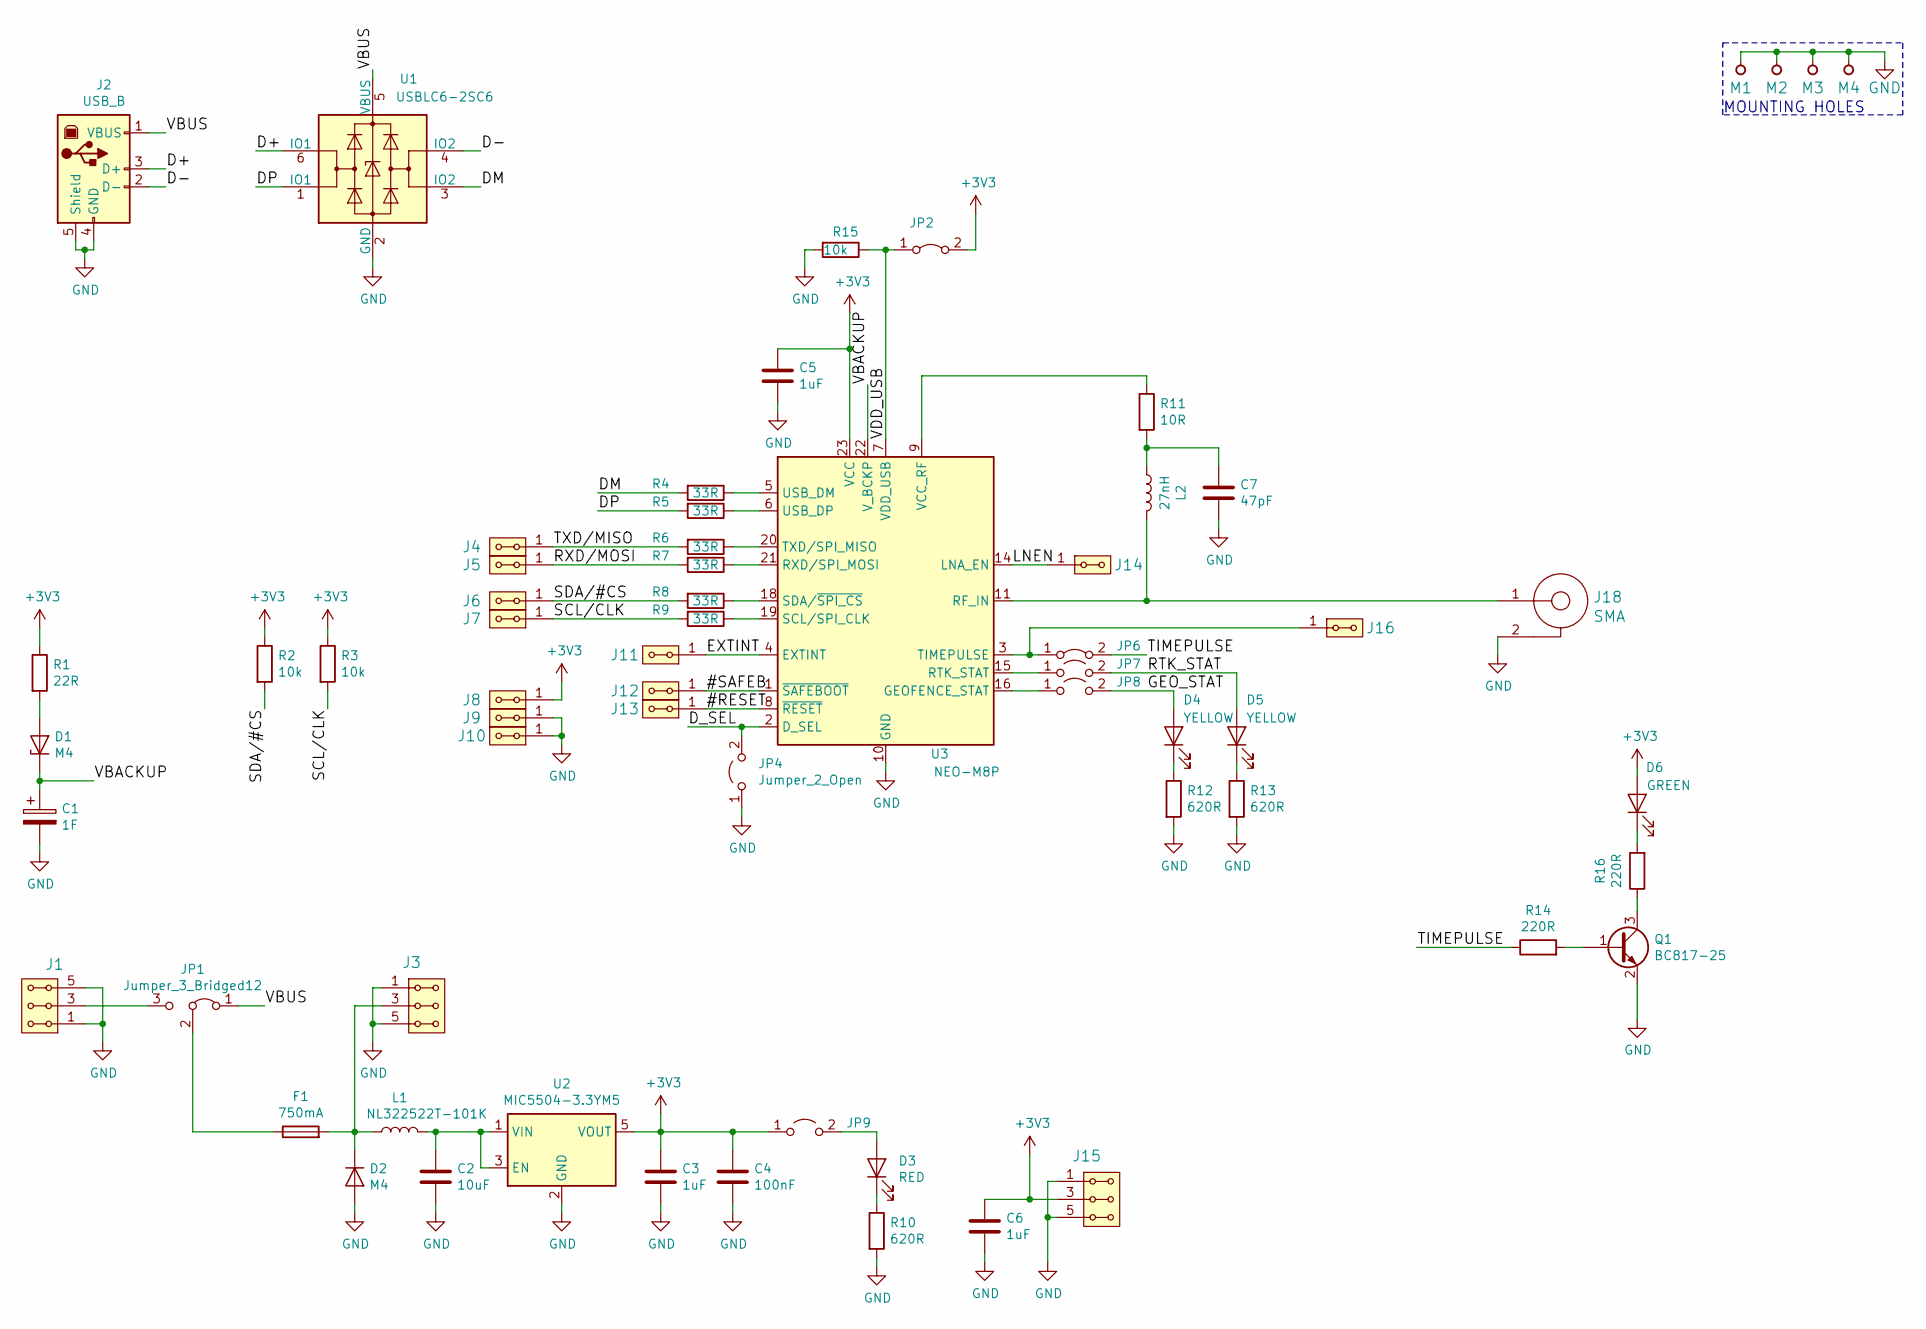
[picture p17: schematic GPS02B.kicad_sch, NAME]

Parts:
C1: 1F; CP_Radial_D8.0mm_P3.50mm
C2: 10uF; SMD-0805
C3, C5, C6: 1uF; SMD-0805
C4: 100nF; SMD-0805
C7: 47pF; SMD-0805
D1, D2: M4; D_SMA
D3: RED; LED_1206
D4, D5: YELLOW; LED_1206
D6: GREEN; LED_1206
F1: 750mA; 1812
J1, J3, J15: HEADER_2x03_PARALLEL; Straight_2x03
J2: USB_B; USB_B_OST_USB-B1HSxx_Horizontal
J4, J5, J6, J7, J8, J9, J10, J11, J12, J13, J14, J16: HEADER_2x01_PARALLEL; Straight_2x01
J18: SMA; SMA6251A13G50
JP1: Jumper_3_Bridged12; Straight_1x03
JP2, JP6: Jumper_2_Bridged; Straight_1x02
JP4: Jumper_2_Open; SolderJumper-2_P1.3mm_Open_RoundedPad1.0x1.5mm
JP7, JP8, JP9: Jumper_2_Open; Straight_1x02
L1: NL322522T-101K; L_1210_3225Metric
L2: 27nH; L_0402_1005Metric
M1, M2, M3, M4: HOLE; MountingHole_3mm
Q1: BC817-25; SOT-23
R1: 22R; SMD-0805
R2, R3, R15: 10k; SMD-0805
R4, R5, R6, R7, R8, R9: 33R; SMD-0805
R10, R12, R13: 620R; SMD-0805
R11: 10R; SMD-0805
R14, R16: 220R; SMD-0805
U1: USBLC6-2SC6; SOT-23-6
U2: MIC5504-3.3YM5; SOT-23-5
U3: NEO-M8P; ublox_NEO

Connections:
+3V3: C3.1, C4.1, C5.1, C6.1, D6.2 (A), J8.1, J8.2, J15.3, J15.4, JP2.2 (B), JP9.1 (A), R1.1, R2.1, R3.1, U2.5 (VOUT), U3.23 (VCC)
/#RESET: J13.1, J13.2, U3.8 (~RESET)
/#SAFEB: J12.1, J12.2, U3.1 (~SAFEBOOT)
/D+: J2.3 (D+), U1.6 (IO1)
/D-: J2.2 (D-), U1.4 (IO2)
/DM: R4.2, U1.3 (IO2)
/DP: R5.2, U1.1 (IO1)
/D_SEL: JP4.2 (B), U3.2 (D_SEL)
/EXTINT: J11.1, J11.2, U3.4 (EXTINT)
/GEO_STAT: D4.2 (A), JP8.2 (B)
/LNEN: J14.1, J14.2, U3.14 (LNA_EN)
/RTK_STAT: D5.2 (A), JP7.2 (B)
/RXD/MOSI: J5.1, J5.2, R7.2
/SCL/CLK: J7.1, J7.2, R3.2, R9.2
/SDA/#CS: J6.1, J6.2, R2.2, R8.2
/TIMEPULSE: JP6.2 (B), R14.1
/TXD/MISO: J4.1, J4.2, R6.2
/VBACKUP: C1.1, D1.1 (K), U3.22 (V_BCKP)
/VBUS: J2.1 (VBUS), JP1.1 (A), U1.5 (VBUS)
/VDD_USB: JP2.1 (A), R15.1, U3.7 (VDD_USB)
GND: C1.2, C2.2, C3.2, C4.2, C5.2, C6.2, C7.2, D2.2 (A), J1.1, J1.2, J1.5, J1.6, J2.4 (GND), J2.5 (Shield), J3.1, J3.2, J3.5, J3.6, J9.1, J9.2, J10.1, J10.2, J15.1, J15.2, J15.5, J15.6, J18.2, JP4.1 (A), M1.1, M2.1, M3.1, M4.1, Q1.2 (E), R10.2, R12.2, R13.2, R15.2, U1.2 (GND), U2.2 (GND), U3.10 (GND), U3.12 (GND), U3.13 (GND), U3.24 (GND)
unnamed: C2.1, L1.2, U2.1 (VIN), U2.3 (EN)
unnamed: C7.1, L2.1, R11.2
unnamed: D1.2 (A), R1.2
unnamed: D2.1 (K), F1.2, J3.3, J3.4, L1.1
unnamed: D3.1 (K), R10.1
unnamed: D3.2 (A), JP9.2 (B)
unnamed: D4.1 (K), R12.1
unnamed: D5.1 (K), R13.1
unnamed: D6.1 (K), R16.2
unnamed: F1.1, JP1.2 (C)
unnamed: J1.3, J1.4, JP1.3 (B)
unnamed: J16.1, J16.2, JP6.1 (A), U3.3 (TIMEPULSE)
unnamed: J18.1, L2.2, U3.11 (RF_IN)
unnamed: JP7.1 (A), U3.15 (RTK_STAT)
unnamed: JP8.1 (A), U3.16 (GEOFENCE_STAT)
unnamed: Q1.1 (B), R14.2
unnamed: Q1.3 (C), R16.1
unnamed: R4.1, U3.5 (USB_DM)
unnamed: R5.1, U3.6 (USB_DP)
unnamed: R6.1, U3.20 (TXD/SPI_MISO)
unnamed: R7.1, U3.21 (RXD/SPI_MOSI)
unnamed: R8.1, U3.18 (SDA/~SPI_CS)
unnamed: R9.1, U3.19 (SCL/SPI_CLK)
unnamed: R11.1, U3.9 (VCC_RF)

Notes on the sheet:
MOUNTING HOLES

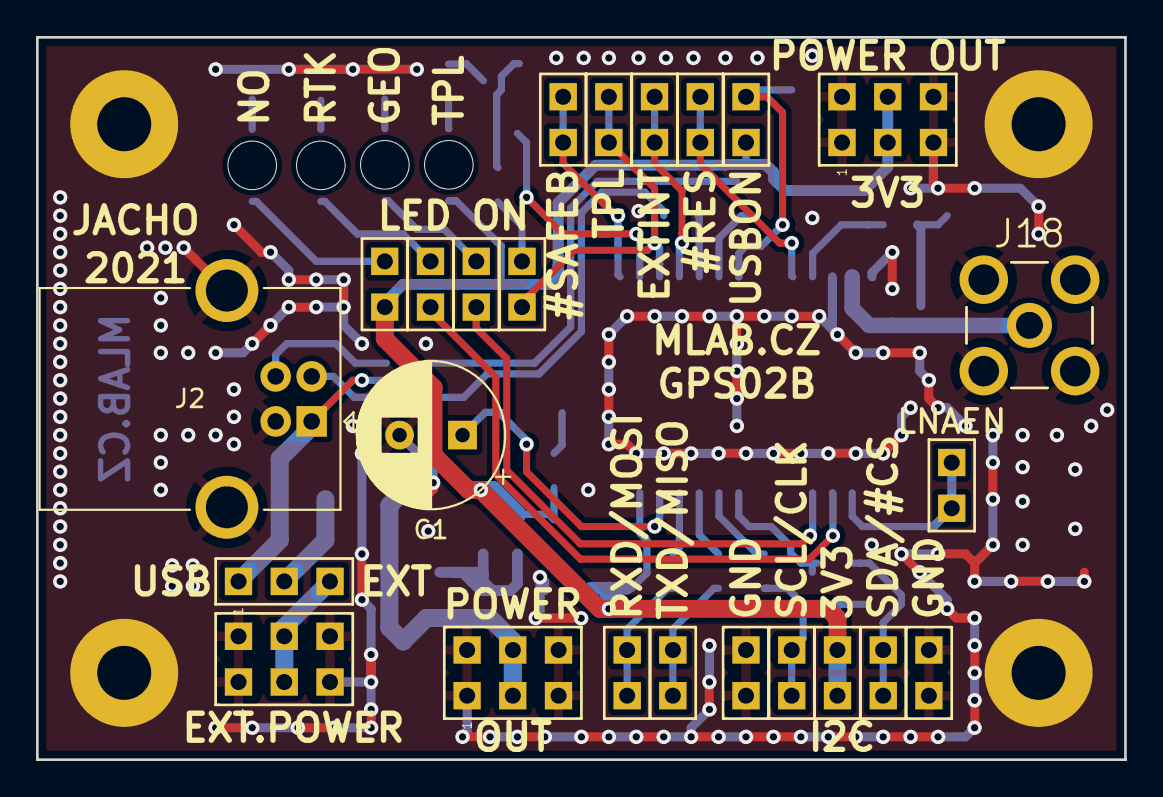
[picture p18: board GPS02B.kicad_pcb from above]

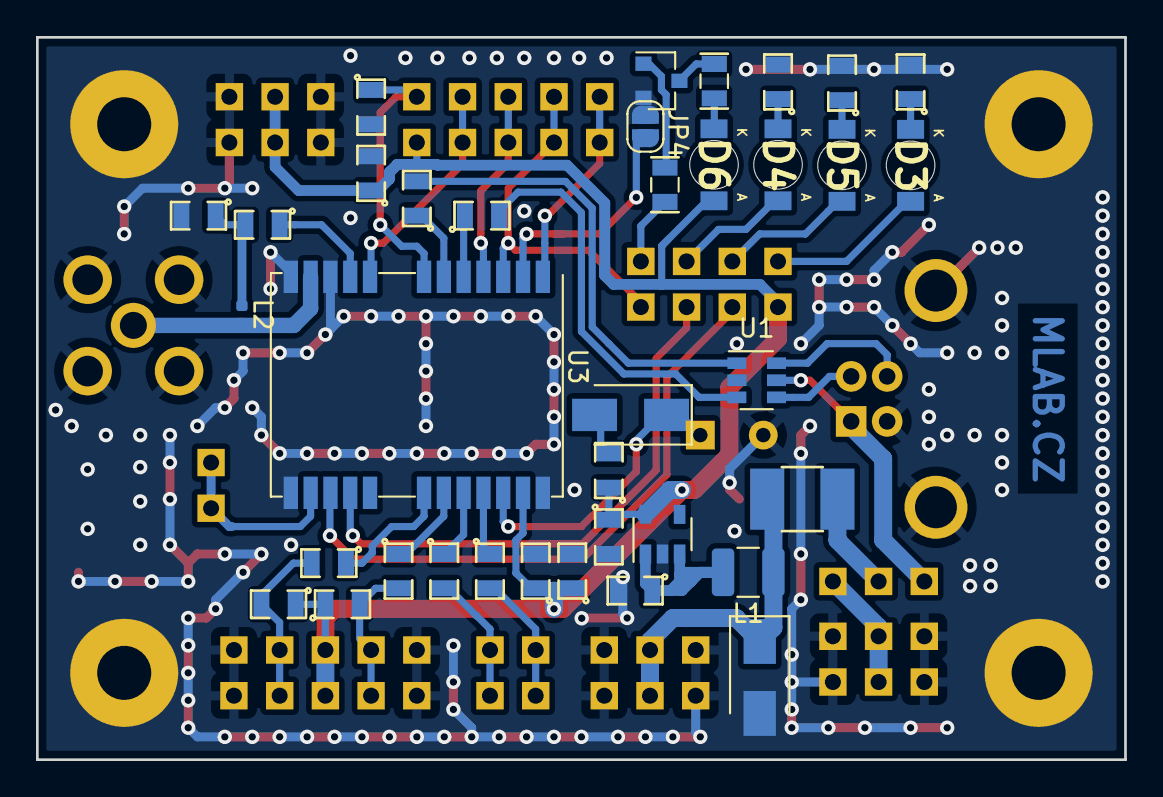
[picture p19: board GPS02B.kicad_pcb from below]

Board: 2 copper layers, 60.5 x 40.1 mm, 64 parts (36 on the bottom side), 45 nets.

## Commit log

2020-06-01 [MLABweb] Documentation edits; GPS02A
    [GPS02A.kicad_pcb, GPS02A.sch]
2020-06-01 Edit PCB
    [GPS02A.kicad_pcb]
2020-06-03 GPS02A BOM
    [GPS02A.sch]
2021-06-07 Kicad version update updating title block
    [GPS02A.kicad_sch, GPS02A.sch]
2021-06-20 Update PCB component parameters from schematics.
    [GPS02A.kicad_pcb]
2021-07-20 Edit #5 #4 #3 #1
    [GPS02A.kicad_pcb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]
2021-11-11 Edit bom
    [GPS02B.kicad_pcb, GPS02B.kicad_sch]
2021-11-24 Edit labels
    [GPS02B.kicad_pcb]
2022-04-06 Update actions products
    [GPS02B-B_Cu.gbr, GPS02B-B_Mask.gbr, GPS02B-Edge_Cuts.gbr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]
2022-08-14 Update link to datasheet Update titleblock.
    [GPS02B.kicad_sch]
